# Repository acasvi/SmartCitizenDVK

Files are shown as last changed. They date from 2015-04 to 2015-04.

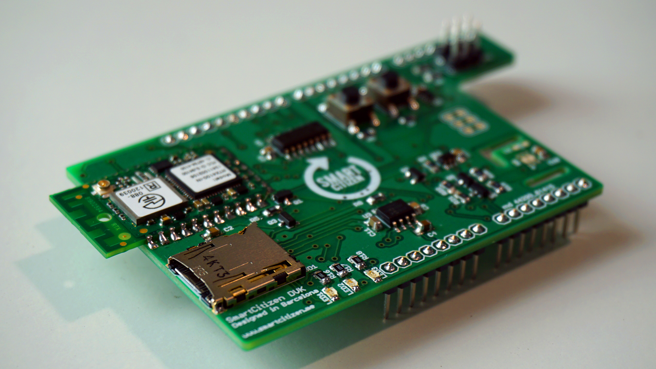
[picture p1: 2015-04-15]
img.jpg

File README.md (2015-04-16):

Smart Citizen Kit DVK
=====================

**[Smart Citizen Kit](https://github.com/fablabbcn/Smart-Citizen-Kit) Develoment Kit (DVK) for [RTX4100](http://www.rtx.dk/RTX41xx_Wi-Fi_modules-3921.aspx) and [Arduino Due](http://arduino.cc/en/Main/arduinoBoardDue)**

SCK_DVK

*The Smart Citizen DVK is an Arduino Shield for the Arduino DUE and the upcoming Arduino Zero aimed to help developers prototype applications for the new Smart Citizen Kit Data Board 2.0. It contains a RTX4100 low-power Wi-Fi module, an SD card socket and a digital temperature and humidity sensor.*

## First Steps

### Installing the toolchain

The tool chain includes primarily a pre-processor, a compiler, and a linker. The RTX41xx relies on the GCC ARM Embedded tool chain from ARM.

Prior to installation, download the GNU tools for ARM embedded processors installation file from: https://launchpad.net/gcc-arm-embedded/+milestone/4.7-2013-q3-update

Download the `gcc-arm-none-eabi-4_7-2013q3-20130916-win32.exe` file, save to disk and run the `.exe` file. 

Don't forget to click “Add path to environment variable” checkbox at the end of the installation.

Refer to **[RTX4100_User_Guide_Tools_Installation_UG2.pdf](https://github.com/fablabbcn/SmartCitizenDVK/blob/master/Documentation/RTX4100/RTX4100_User_Guide_Tools_Installation_UG2.pdf)** for a further explanation about installation the toolchain and SDK.

### Installing the SDK

After installing the Tool Chain, it is time to install the RTX41xx Software Development Kit (SDK). 

Go to the following link: [www.rtx.dk/LPW/RTX4100](http://www.rtx.dk/LPW/RTX4100) and click on **DOWNLOAD** link on top right.

You have to sign up to download the latest SDK `AmelieSdk_v1.6.0.58.exe`.

Once you have downloaded open the `.exe` to start the installer.

The SDK download from RTX includes the following items:

* Sample code implementing the following applications: 
    * Blinky: Small example application that uses a timer to flash a LED on the demo board.
    * TCP Server/client
    * UDP Server/client
    * Terminal Application
    * 3 different Temperature Sensor implementations, demonstrating various low power capabilities.
    * TempSensorSoftApCfg, demonstrating how it is possible to configure a module by booting it in SoftAP mode with telnet support.
    * SoftApTcpServer, demonstrating an AP implementation with TCP server.
    * WebServer, demonstrating a very simple WEB server implementation.
    * Tcp2Uart, demonstrates a simple implementation of a data pipe
    * Cloud reference applications, demonstrating various cloud solutions 
    * Header files for available APIs.
    * Build environment: Build scripts, linker files etc. are provided for ARM GCC Em-bedded tool chain.
    * RTX EAI Port Server: PC application used for communicating with the hardware.
    * CoLA Controller DLL: Used for selecting active image and updating firmware.
    * CoLA Controller GUI: Example application using the DLL. In the end product the DLL could be used directly from e.g. an Eclipse IDE.

It is assumed that the SDK has been installed in c:\AmelieSdk\vX.XX, and the following description of the folder structure is relative to this location.

The following folders are at top level: 

* **3Party** – includes source files from 3rd parties. The most important file found here is the “efm32lib” from Energy Micro which is used to access the peripherals of the MCU.
* **ColaController** – The PC tool used to download Co-Located Applications to the module via the UART.
* **Components** – Source code to some common components used when the CoLA is built.
* **Documents** – Documentation folder.
* **Include** – Common header files.
* **Projects** – This is where you find the reference CoLA applications
* **Tools** – A set of tools used when the CoLA is built. This also includes the RtxBuild system used for the build process.

In the Project folder (Projects\Amelie\COLApps) you find the following folders:

* **Apps** – A set of reference applications 
	* Blinky – The source code for the Blinky application
	* Blinky/Build/RTX4100_WSAB – Build folder for RTX4100 module on WSAB.
	* Blinky/Build/RTX4140_WSAB – Build folder for RTX4140 module on WSAB.
* **Config** – This folder holds various configuration header files required to build the reference applications.
* **Rsx** – PC tool for API mail trace via UART.
* **Scripts** – build/linker scripts.

In the Components folder (Projects\Amelie\Componets) you find the following folders: 

* **Api** – Some API header files
* **ApiMps** – API mail packing and sending helper functions
* **Drivers** – Implementation of various hardware drivers 
* **PtApps** – Protothread based application framework used by all reference applica-tions except Blinky. 

Refer to **[RTX4100_User_Guide_Tools_Installation_UG2.pdf](https://github.com/fablabbcn/SmartCitizenDVK/blob/master/Documentation/RTX4100/RTX4100_User_Guide_Tools_Installation_UG2.pdf)** for a further explanation about installation the toolchain and SDK.

#### Application Development

For start with the **application development** refer to chapter 4 on [RTX4100_User_Guide_Application_Development_UG3.pdf](https://github.com/fablabbcn/SmartCitizenDVK/blob/master/Documentation/RTX4100/RTX4100_User_Guide_Application_Development_UG3.pdf)

For **terminal commands to configure WIFI** module refer to chapter 5 on [RTX4100_User_Guide_Module_Evaluation_UG1.pdf](https://github.com/fablabbcn/SmartCitizenDVK/blob/master/Documentation/RTX4100/RTX4100_User_Guide_Application_Development_UG3.pdf)

For **API used to program Co-Located Applications (CoLA)** on top of the Amelie Wi-Fi platform refer to [AmelieApi_V0106_N0052.pdf](https://github.com/fablabbcn/SmartCitizenDVK/blob/master/Documentation/RTX4100/AmelieApi_V0106_N0052.pdf)

## Software

All the boards come with:

* Arduino firmware *[SmartCitizen_DVK.ino](https://github.com/fablabbcn/SmartCitizenDVK/tree/master/Firmware)* uploaded. 
* RTX firmware uploaded
* CoLA application for terminal communication with WIFI module uploaded, for available **terminal commands** refer to chapter 5 on *[RTX4100_User_Guide_Module_Evaluation_UG1.pdf](https://github.com/fablabbcn/SmartCitizenDVK/blob/master/Documentation/RTX4100/RTX4100_User_Guide_Module_Evaluation_UG1.pdf)*

To use the RTX Shield connect an usb cable in the programming port of the Arduino Due, the one closest to the DC power jack.

As you can see, the RTX shield has two push buttons, **S1** and **S2**. With this two buttons you can change between 4 modes of operation:

####MODE 1

This is the default mode when you connect the board, green LED is ON. This mode sendsthrough USB-Serial, at 9600 bauds, the values captured by the temperature and humidity sensors and tells you if a SD Card is detected or not. You can find this values in the `main()` function of `SmartCitizen_DVK.ino`.

####MODE 2

If **S1** button is pushed, the green LED starts to blinking. You are on terminal mode. If a CoLa app for terminal communication is uploaded, yelllow LED ON, you can talk through USB-serial with the RTX WIFI module. If you push again S1, you'll go back to **MODE 1**.

####MODE 3

If **S2** button is pushed ,the blue LED goes ON, you can now upload CoLA applications with **ColaController**, the PC tool used to download Co-Located Applications to the module via the UART. You can find this tool on **ColaController** folder inside **Amelie SDK** folder.

####MODE 4

If **S2** button is pushed again, the green and blue LEDs goes ON, you will enter in RTX firmware uploading mode and the blue LED will start blinking.

To perform the Firmware update:

1. Download the firmware file **RTX41xx_Platform_Firmware_Update_Pack_v1.6.0.52.zip** from the RTX [download center](http://www.rtx.dk/Download_Center_Login-3980.aspx). 
2. Unzip the file to your harddrive. As this document is included in the above ZIP file you have probably already downloaded the file.

*NOTE: Each time you plug the arduino due with the shield to your computer automatically reses the mode to mode 1.*

### Existing software

* [Smart Citizen Kit firmware](https://github.com/fablabbcn/Smart-Citizen-Kit) for the Ambient Sensor Board 1.0-1.2 *(MCU ATMEGA32U4)*
* [Smart Citizen Kit RTX4100 Application - BETA](https://github.com/fablabbcn/SmartCitizenRTX4100)

## Hardware

SmartCitizen DVK shield design files are available [here](https://github.com/fablabbcn/SmartCitizenDVK/hardware).

### RTX4100 - Low power wifi module

* [http://www.rtx.dk/RTX41xx_Wi-Fi_modules-3921.aspx](http://www.rtx.dk/RTX41xx_Wi-Fi_modules-3921.aspx)

* [http://www.rtx.dk/Wi-Fi_Documentation-4028.aspx](http://www.rtx.dk/Wi-Fi_Documentation-4028.aspx)

The RTX41xx Wi-Fi Module is a low power solution, which is achieved through the use of the  Energy Micro Gecko and Atheros AR4100 Wi-Fi SiP.

**The I/O's include:**

* Power supply pins
* ADC ports, DAC ports
* GPIO ports
* UART, SPI, I2C
* Timers

#### NC7SZ157P6X – MUX

[http://www.mouser.com/ds/2/149/NC7SZ157-96268.pdf](http://www.mouser.com/ds/2/149/NC7SZ157-96268.pdf)

The mux is used to select from Arduino which serial port of the RTX4100 you want to use.

You can select between two serial ports:

* **LEU1**: (LEUART) is used for the Terminal application (such at Putty), for example.
* **US1**: (USART) is used for the COLApp loading, SW debugging and Platform updates (using the COLApp Controller)

#### MCP1725-3002E/SN LDO REGULATOR

[http://ww1.microchip.com/downloads/en/DeviceDoc/22026b.pdf](%22http:)

3V fixed voltage regulator

#### CD74HC4050M High-to-Low Voltage Level Converter

[http://www.mouser.com/ds/2/405/schs205i-101882.pdf](http://www.mouser.com/ds/2/405/schs205i-101882.p)

IC used as logic level converter between Arduino and the RTX4100 module.

#### SDCARD

[http://www.mouser.com/ds/2/185/e60900232-38395.pdf](http://www.mouser.com/ds/2/185/e60900232-38395.pdf)

To hold the SD card we are using the DM3CS holder. The SD card is powered at 3V and communicates with the RTX4100 through SPI protocol.

#### SHT21 Humidity and Temperature Sensor IC

[http://www.sensirion.com/fileadmin/user_upload/customers/sensirion/Dokumente/Humidity/Sensirion_Humidity_SHT21_Datasheet_V4.pdf](http://www.sensirion.com/fileadmin/user_upload/customers/s)

#### LEDs

* **LED1 YELLOW:** Connected to RTX4100 pin 27, for testing Blink CoLA example
* **LED2 BLUE:** Connected to Arduino Analog0 pin
* **LED3 GREEN:** Connected to Arduino Analog1 pin

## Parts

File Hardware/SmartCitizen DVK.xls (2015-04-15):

ITEM | Manufacturer | Manufacturer Part | Name | Designator | Qty | Description | Case
1 | VISHAY | VJ0805Y104MXXAC | Capacitors | C1, C2, C3, C10, C29 | 5 | 100n | 805
2 | VISHAY | VJ0805V475MXQTW1BC |  | C4 | 1 | 4.7u | 805
3 | VISHAY | VJ0805Y102JXQPW1BC |  | C9 | 1 | 1n | 805
4 | VISHAY | VJ0805Y105KXQTW1BC |  | C11 | 1 | 1u | 805
5 | VISHAY | PHT0805Y1002BGT | Resistors | R1, R4, R7, R19, R20, R21, R22 | 7 | 10k | 805
6 | VISHAY | PHT0805Y1001BGT |  | R2, R3, R5, R16, R17, R18 | 6 | 1k | 805
7 | YAGEO | RT0805FRE07100KL |  | R8 | 1 | 100k | 805
8 | Bourns | MH2029-300Y | Magnetic Bead | L1 | 1 | WE-CBF_0805 | 805
9 | RTX | RTX4100 | IC | U1 | 1 | RTX4100 | RTX41X0
10 | FAIRCHILD SEMICONDUCTOR | NC7SZ157P6X |  | U2 | 1 | NC7SV157 | SC70
11 | MICROCHIP | MCP1725-3002E/SN |  | U3 | 1 | MCP1725 | SOIC8
12 | TEXAS INSTRUMENTS | CD74HC4050M |  | U4 | 1 | 4050D | SO16
13 | TEXAS INSTRUMENTS | SN74AHC1G125DBVR |  | U11 | 1 | 74AHC1G125 | SOT23-5
14 | Hirose Electric Co Ltd | DM3AT-SF-PEJM5(11) | Memorizer | SD1 | 1 | PC card,right angle | DM3AT
15 | DIODES INC. | ZXMN3A01F | Transistors | Q1, Q2, Q5, Q9 | 4 | MOSFET-NCHANNEL | SOT23-3
16 | VISHAY | SI2305CDS-T1-GE3 |  | Q3 | 1 | MOSFET-PCHANNEL | SOT23-3
17 | TE Connectivity | 4-1437565-1 | Sensors | S1, S2 | 2 | SWITCH-MOMENTARY-2 | TACTILE_SWITCH_TALL
18 | SENSIRION | SHT21 |  | S3 | 1 | Temp/Humidity Sensor | DFN300X300X110-7N
19 | DIALIGHT | 598-8150-107F | LED | LED1 | 1 | YELLOW | 805
20 | DIALIGHT | 598-8191-107F |  | LED2 | 1 | BLUE | 805
21 | DIALIGHT | 598-8160-107F |  | LED3 | 1 | GREEN | 805
22 | HARWIN | M20-7830346 | Pin Header | SPI | 1 | PCB Socket2.54（2*3）180° H8.5 1U gold black PBT material (Female connector) | 2X03
23 | FCI | 69190-410HLF |  | PWMH | 1 | Headers & Wire Housings 10P SR UNSHRD HRD TIN OVER NI | 1X10
24 | FCI | 69190-403 |  | JP1, JP2 | 2 | Headers & Wire Housings 3P SR UNSHRD HRD TIN OVER NI | 1X03
25 | FCI | 68000-408HLF |  | ADCL, COMMUNICATION, POWER, PWML | 4 | Headers & Wire Housings 8P SR UNSHRD HRD TIN OVER NI | 1X08

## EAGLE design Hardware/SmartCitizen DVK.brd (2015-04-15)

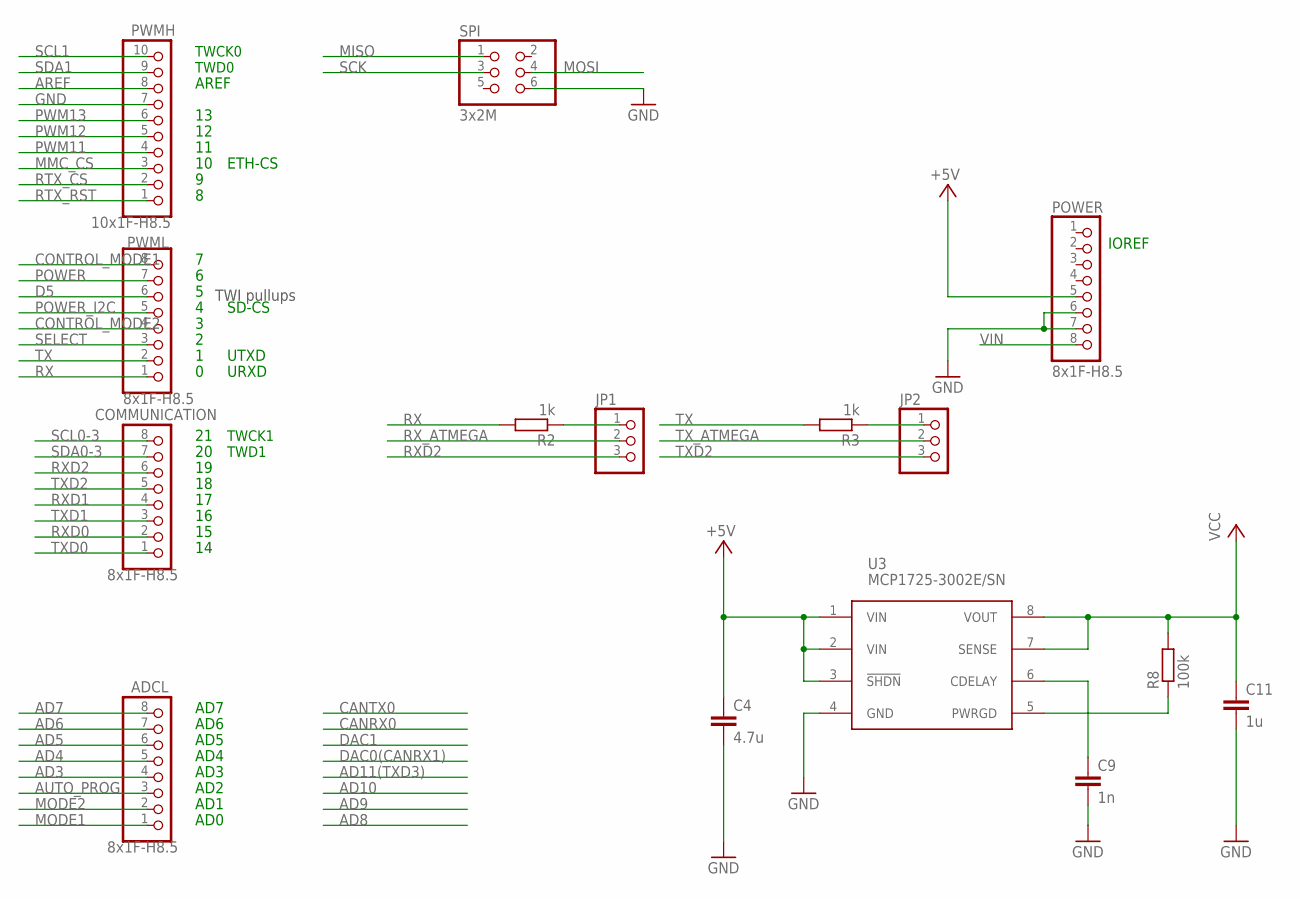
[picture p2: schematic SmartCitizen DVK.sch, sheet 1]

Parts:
ADCL: 8x1F-H8.5; 1X08
C4: 4.7u; C0805
C9: 1n; C0805
C11: 1u; C0805
COMMUNICATION: 8x1F-H8.5; 1X08
JP1, JP2: PINHD-1X3; 1X03
POWER: 8x1F-H8.5; 1X08
PWMH: 10x1F-H8.5; 1X10
PWML: 8x1F-H8.5; 1X08
R2, R3: 1k; R0805
R8: 100k; R0805
SPI: 3x2M; 2X03
U3: MCP1725-3002E/SN; SOIC8

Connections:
+5V: C4.1, POWER.5, U3.1 (VIN), U3.2 (VIN), U3.3 (!SHDN); also elsewhere on the board
AD3: ADCL.4
AD4: ADCL.5
AD5: ADCL.6
AD6: ADCL.7
AD7: ADCL.8
AREF: PWMH.8
AUTO_PROG: ADCL.3; also elsewhere on the board
CONTROL_MODE1: PWML.8; also elsewhere on the board
CONTROL_MODE2: PWML.4; also elsewhere on the board
D5: PWML.6
GND: C4.2, C9.2, C11.2, POWER.6, POWER.7, PWMH.7, SPI.6, U3.4 (GND); also elsewhere on the board
MISO: SPI.1; also elsewhere on the board
MMC_CS: PWMH.3; also elsewhere on the board
MODE1: ADCL.1; also elsewhere on the board
MODE2: ADCL.2; also elsewhere on the board
MOSI: SPI.4; also elsewhere on the board
unnamed: JP1.1, R2.1
unnamed: JP2.1, R3.1
unnamed: C9.1, U3.6 (CDELAY)
unnamed: R8.1, U3.5 (PWRGD)
POWER: PWML.7; also elsewhere on the board
POWER_I2C: PWML.5; also elsewhere on the board
PWM11: PWMH.4
PWM12: PWMH.5
PWM13: PWMH.6
RTX_CS: PWMH.2; also elsewhere on the board
RTX_RST: PWMH.1; also elsewhere on the board
RX: PWML.1, R2.2
RXD0: COMMUNICATION.2
RXD1: COMMUNICATION.4
RXD2: COMMUNICATION.6, JP1.3
RX_ATMEGA: JP1.2; also elsewhere on the board
SCK: SPI.3; also elsewhere on the board
SCL0-3: COMMUNICATION.8
SCL1: PWMH.10; also elsewhere on the board
SDA0-3: COMMUNICATION.7
SDA1: PWMH.9; also elsewhere on the board
SELECT: PWML.3; also elsewhere on the board
TX: PWML.2, R3.2
TXD0: COMMUNICATION.1
TXD1: COMMUNICATION.3
TXD2: COMMUNICATION.5, JP2.3
TX_ATMEGA: JP2.2; also elsewhere on the board
VCC: C11.1, R8.2, U3.7 (SENSE), U3.8 (VOUT); also elsewhere on the board
VIN: POWER.8

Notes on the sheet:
TWI pullups
TWCK1
TWD1
IOREF
TWCK0
TWD0
AD1
AD2
AD3
AD4
AD5
AD6
AD0
AREF
AD7
SD-CS
UTXD
URXD
ETH-CS

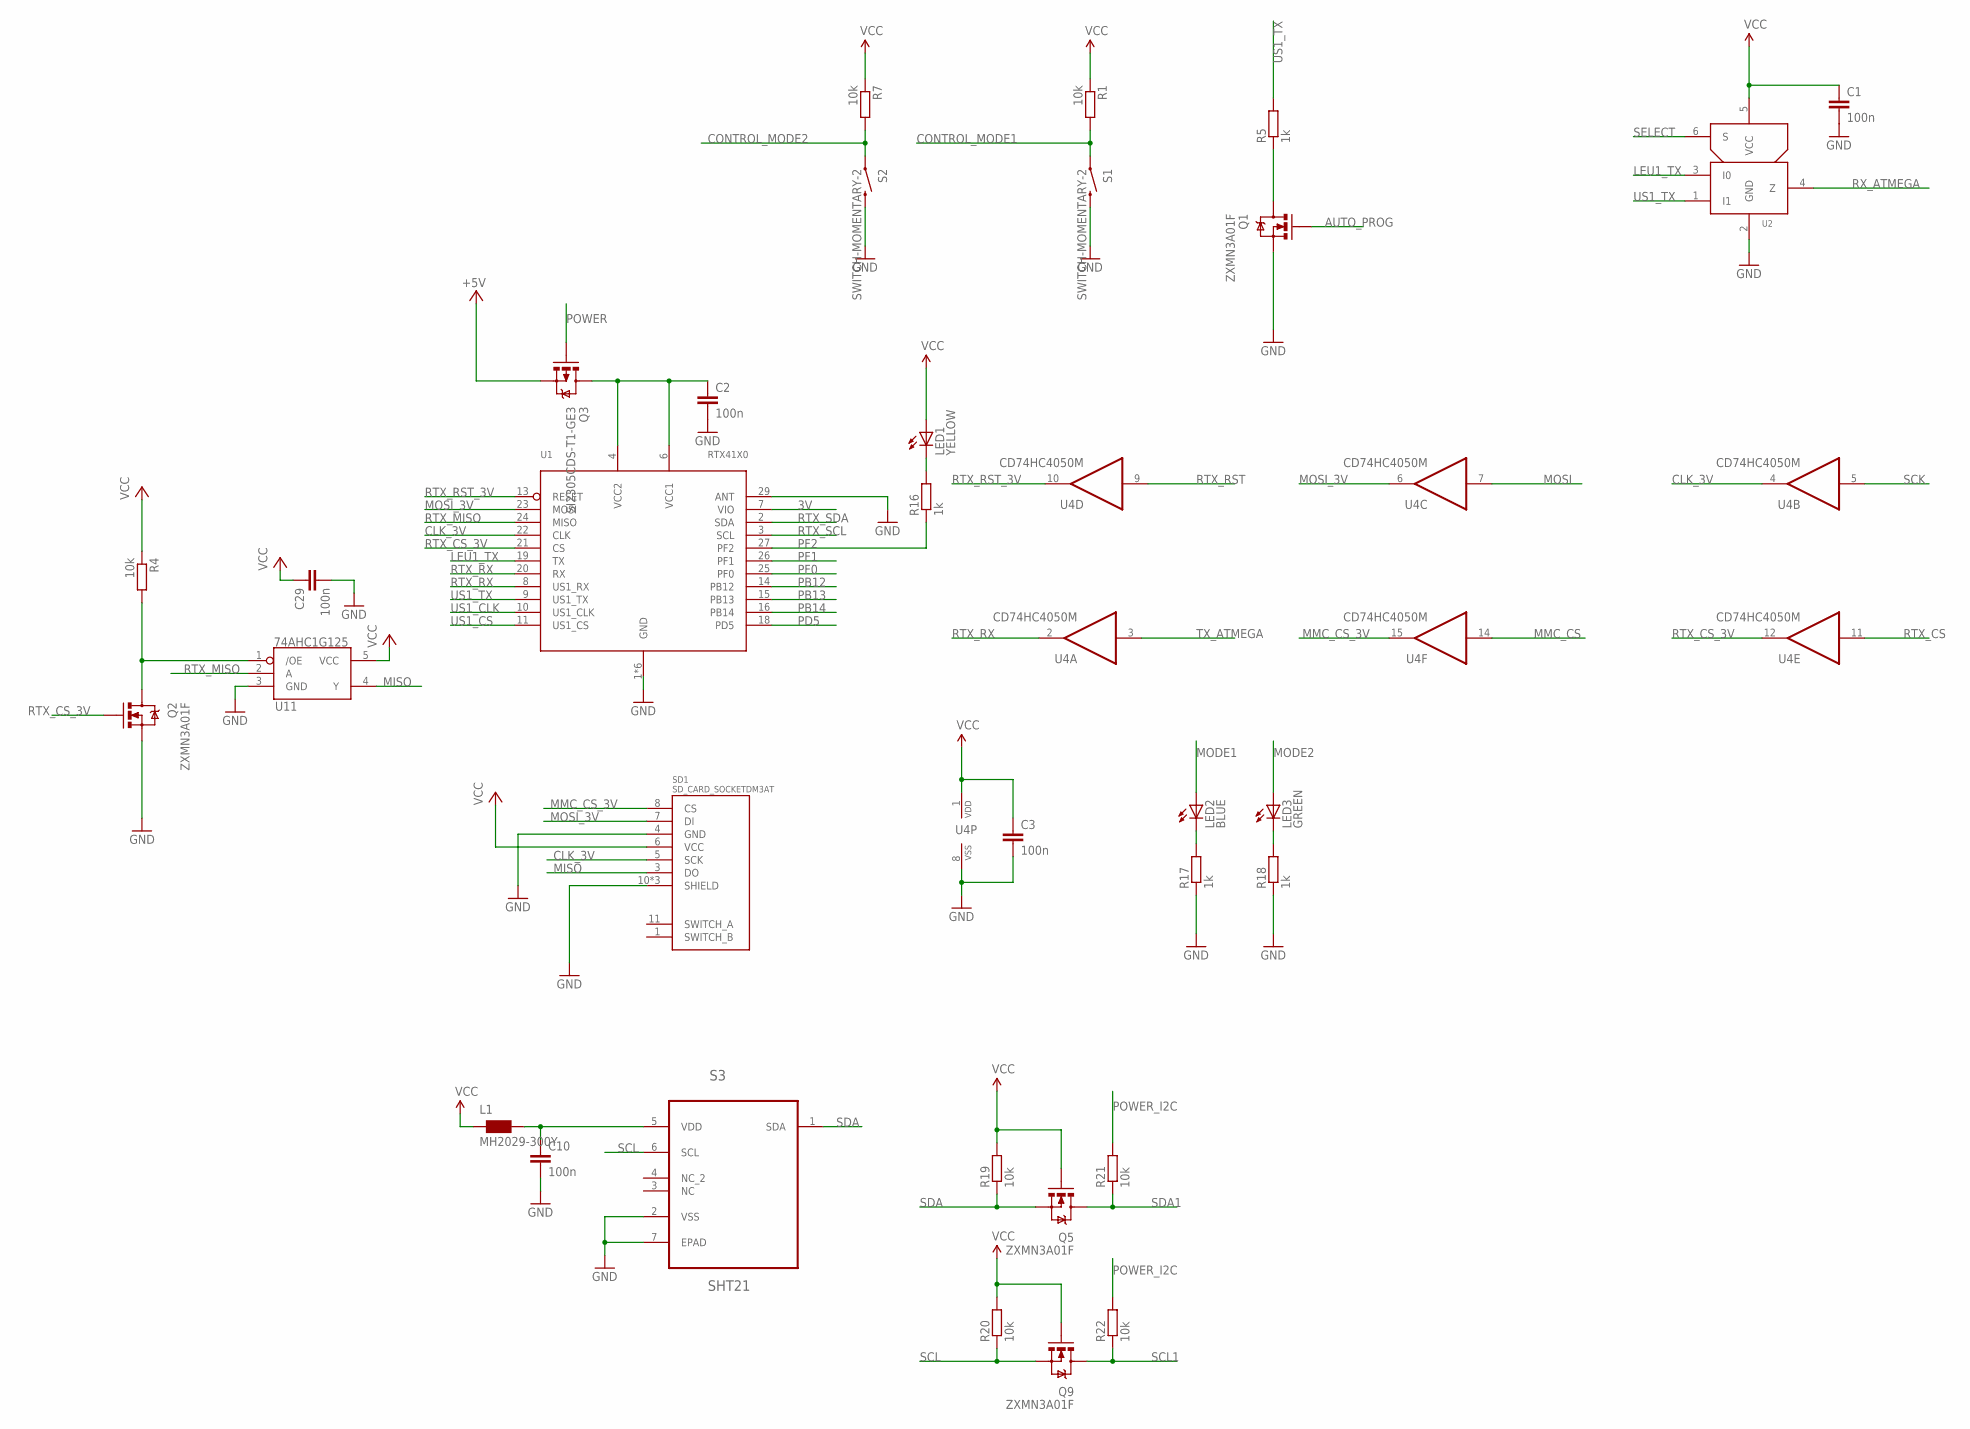
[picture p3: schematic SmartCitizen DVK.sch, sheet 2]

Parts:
C1, C2, C3, C10, C29: 100n; C0805
L1: MH2029-300Y; 0805
LED1: YELLOW; CHIPLED_0805
LED2: BLUE; CHIPLED_0805
LED3: GREEN; CHIPLED_0805
Q1, Q2, Q5, Q9: ZXMN3A01F; SOT23
Q3: SI2305CDS-T1-GE3; SOT23-3
R1, R4, R7, R19, R20, R21, R22: 10k; R0805
R5, R16, R17, R18: 1k; R0805
S1, S2: SWITCH-MOMENTARY-2; TACTILE_SWITCH_TALL
S3: SHT21; DFN300X300X110-7N
SD1: SD_CARD_SOCKETDM3AT; DM3AT
U1: RTX41X0
U2: NC7SZ157P6X; SC70
U4: CD74HC4050M; SO16
U11: 74AHC1G125; SOT23-5

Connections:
3V: U1.7 (VIO)
+5V: Q3.2 (S); also elsewhere on the board
AUTO_PROG: Q1.1 (G); also elsewhere on the board
CLK_3V: SD1.5 (SCK), U1.22 (CLK), U4.4 (O)
CONTROL_MODE1: R1.2, S1.A2 (1); also elsewhere on the board
CONTROL_MODE2: R7.2, S2.A2 (1); also elsewhere on the board
GND: C1.2, C2.2, C3.2, C10.2, C29.2, Q1.2 (S), Q2.2 (S), R17.1, R18.1, S1.B2 (2), S2.B2 (2), S3.2 (VSS), S3.7 (EPAD), SD1.4 (GND), SD1.10 (SHIELD), SD1.12 (SHIELD), SD1.13 (SHIELD), U1.1 (GND), U1.5 (GND), U1.12 (GND), U1.17 (GND), U1.28 (GND), U1.29 (ANT), U1.30 (GND), U2.2 (GND), U4.8 (VSS), U11.3 (GND); also elsewhere on the board
LEU1_TX: U1.19 (TX), U2.3 (I0)
MISO: SD1.3 (DO), U11.4 (Y); also elsewhere on the board
MMC_CS: U4.14 (I); also elsewhere on the board
MMC_CS_3V: SD1.8 (CS), U4.15 (O)
MODE1: LED2.A; also elsewhere on the board
MODE2: LED3.A; also elsewhere on the board
MOSI: U4.7 (I); also elsewhere on the board
MOSI_3V: SD1.7 (DI), U1.23 (MOSI), U4.6 (O)
unnamed: Q1.3 (D), R5.1
unnamed: LED1.C, R16.2
unnamed: LED2.C, R17.2
unnamed: LED3.C, R18.2
unnamed: C10.1, L1.2, S3.5 (VDD)
unnamed: Q2.3 (D), R4.2, U11.1 (/OE)
PB12: U1.14 (PB12)
PB13: U1.15 (PB13)
PB14: U1.16 (PB14)
PD5: U1.18 (PD5)
PF0: U1.25 (PF0)
PF1: U1.26 (PF1)
PF2: R16.1, U1.27 (PF2)
POWER: Q3.1 (G); also elsewhere on the board
POWER_I2C: R21.2, R22.2; also elsewhere on the board
RTX_CS: U4.11 (I); also elsewhere on the board
RTX_CS_3V: Q2.1 (G), U1.21 (CS), U4.12 (O)
RTX_MISO: U1.24 (MISO), U11.2 (A)
RTX_RST: U4.9 (I); also elsewhere on the board
RTX_RST_3V: U1.13 (RESET), U4.10 (O)
RTX_RX: U1.8 (US1_RX), U1.20 (RX), U4.2 (O)
RTX_SCL: U1.3 (SCL)
RTX_SDA: U1.2 (SDA)
RX_ATMEGA: U2.4 (Z); also elsewhere on the board
SCK: U4.5 (I); also elsewhere on the board
SCL: Q9.2 (S), R20.1, S3.6 (SCL)
SCL1: Q9.3 (D), R22.1; also elsewhere on the board
SDA: Q5.2 (S), R19.1, S3.1 (SDA)
SDA1: Q5.3 (D), R21.1; also elsewhere on the board
SELECT: U2.6 (S); also elsewhere on the board
TX_ATMEGA: U4.3 (I); also elsewhere on the board
US1_CLK: U1.10 (US1_CLK)
US1_CS: U1.11 (US1_CS)
US1_TX: R5.2, U1.9 (US1_TX), U2.1 (I1)
VCC: C1.1, C3.1, C29.1, L1.1, LED1.A, Q5.1 (G), Q9.1 (G), R1.1, R4.1, R7.1, R19.2, R20.2, SD1.6 (VCC), U2.5 (VCC), U4.1 (VDD), U11.5 (VCC); also elsewhere on the board
VCC2: C2.1, Q3.3 (D), U1.4 (VCC2), U1.6 (VCC1)

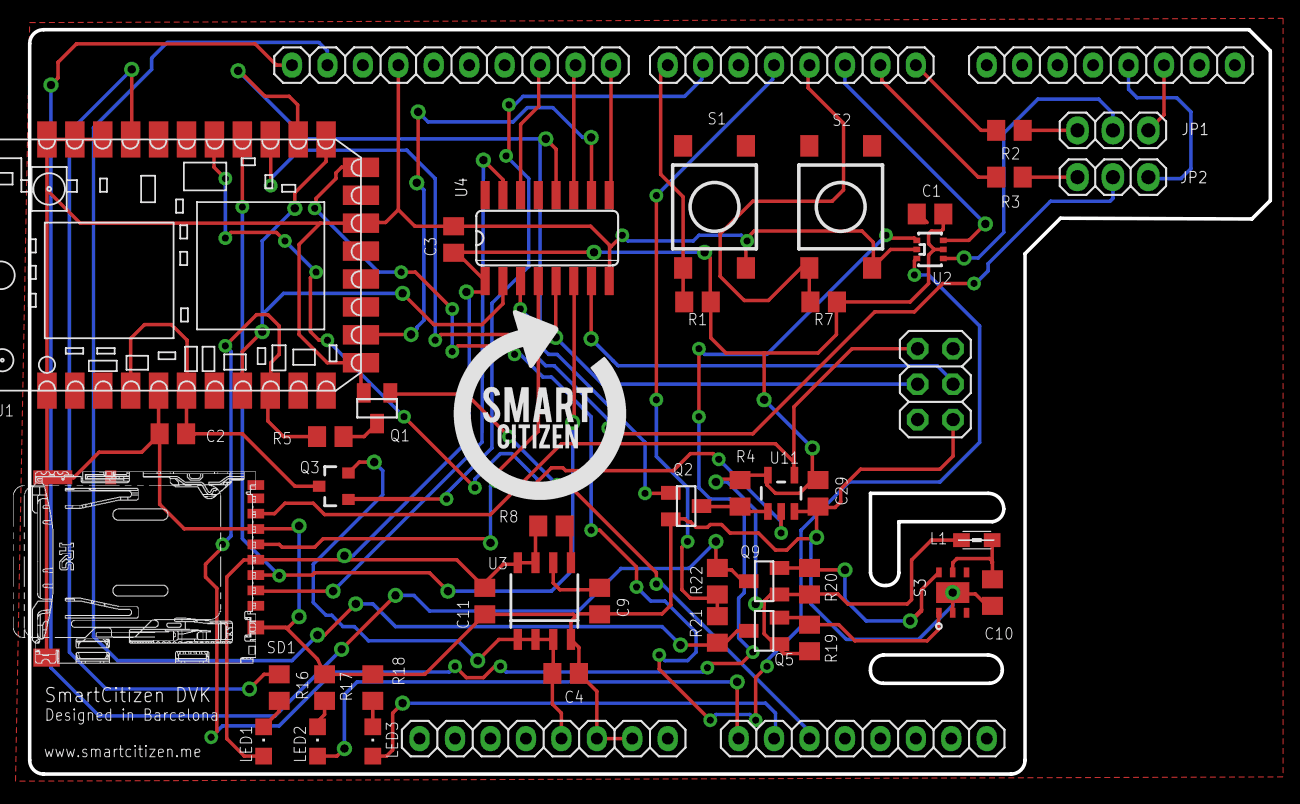
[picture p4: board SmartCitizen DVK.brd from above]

Board: 2 copper layers, 88.9 x 53.3 mm, 48 parts (0 on the bottom side), 48 nets.

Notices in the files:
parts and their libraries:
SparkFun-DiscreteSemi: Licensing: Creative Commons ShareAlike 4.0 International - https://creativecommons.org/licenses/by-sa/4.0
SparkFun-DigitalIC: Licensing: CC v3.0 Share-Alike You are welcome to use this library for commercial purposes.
